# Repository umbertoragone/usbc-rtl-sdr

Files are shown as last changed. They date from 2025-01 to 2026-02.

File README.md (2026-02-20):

# USB-C RTL-SDR mod
An adapter board to convert your RTL-SDR V3 or V4 USB-A (male) to USB-C (female). **Available for purchase on [Tindie](https://www.tindie.com/products/ragone/usb-c-rtl-sdr-v3v4-mod/) or [Lectronz](https://lectronz.com/products/usb-c-rtl-sdr-v3-v4-mod)!**

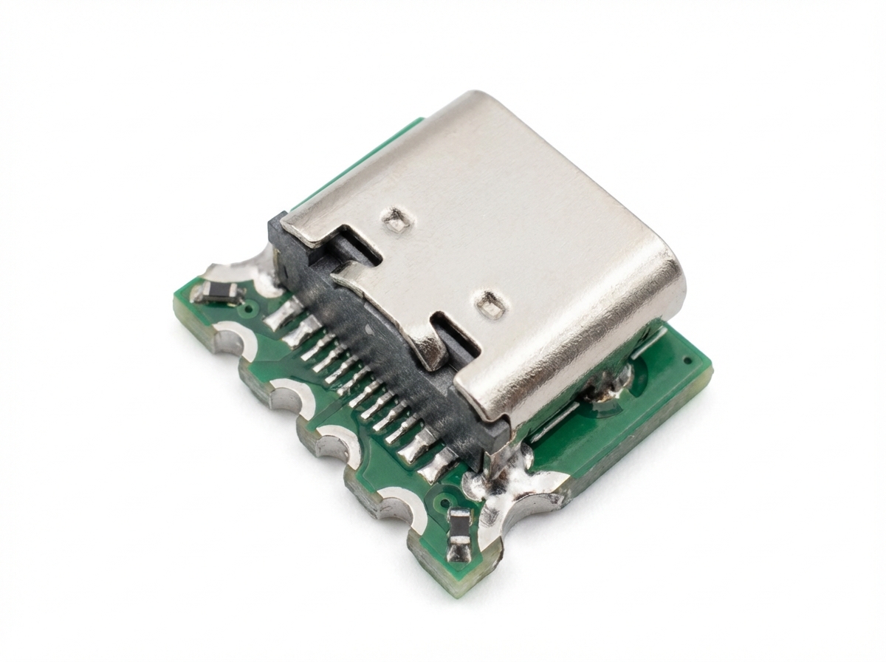
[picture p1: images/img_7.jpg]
USB-C adapter board


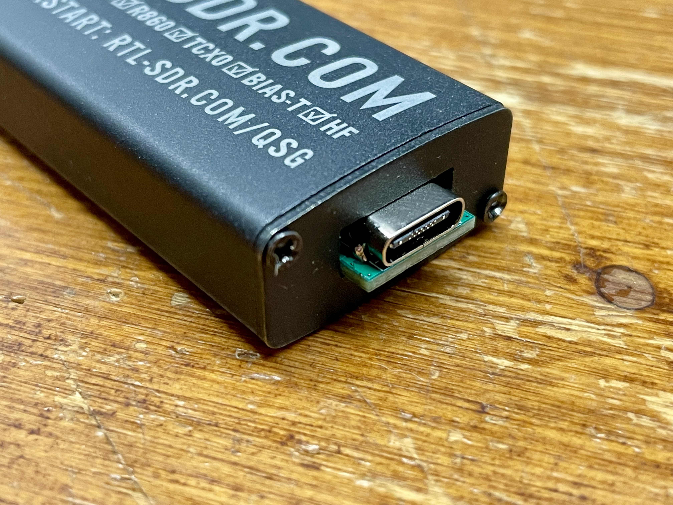
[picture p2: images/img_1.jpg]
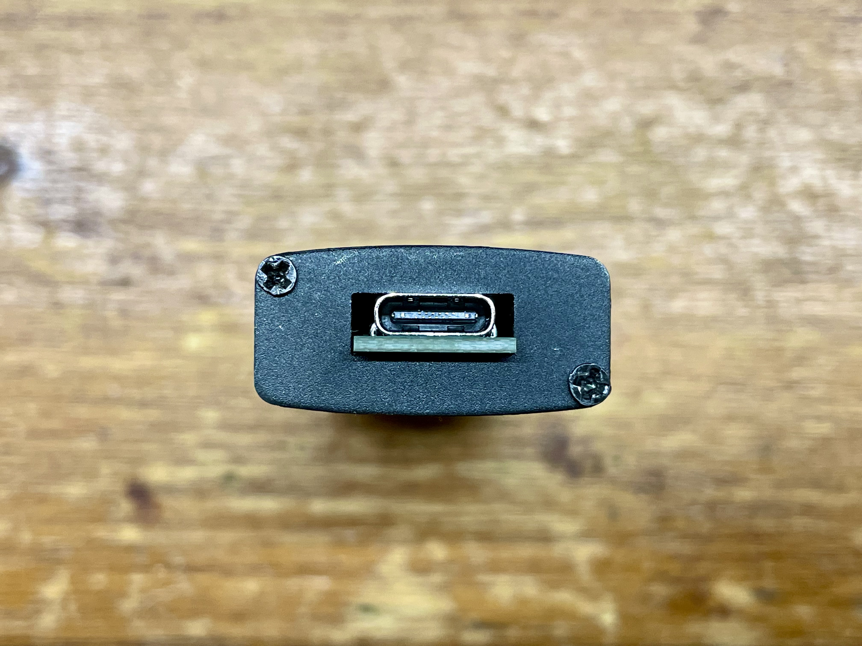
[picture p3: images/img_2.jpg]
 

## Kicad files
If you want to open and modify the original project in Kicad 8 (>=8.0.7), you can find both the `.kicad_sch` and `.kicad_pcb` files in the `kicad` folder in this repository. I recommend you use the latest Kicad 8 version available for better compatibility.

## Gerber files
If you want to fabricate your own PCBs from a PCB manufacturer of your choice, you can go ahead and download the `Gerber-v1.x.zip` file from the `gerber` folder in this repository. Upload it or send it to the PCB fabrication house and select the following specifications (if not already filled out):
- **Layers**: 2
- **PCB Thickness**: 1.2 mm
- **PCB Color**: any (green is usually cheaper and faster to produce, but black also looks nice and might blend with the black outer case)
- **Surface finish**: HASL or ENIG (gold plating)
- **Outer Copper Weight**: 1 oz
- **Via Covering**: Tented
- **Mark on PCB**: Remove Mark (JLCPCB specific, now free of charge)
- **Castellated holes**: Yes

## BOM and assembly

Included in this repository is the HTML BOM (`ibom.html`) to help you in the assembly/soldering process after you received your PCBs. You can [access the Interactive HTML BOM here](https://umbertoragone.github.io/usbc-rtl-sdr/bom/ibom.html), without having to download the .html file. Also, here is the list of components you will have to source and solder yourself:

| Reference(s) | Value | Footprint | LCSC Part # | Qty |
| --- | --- | --- | --- | --- |
| R1, R2 | 5k1 1% | R_0402_1005Metric | [C25905](https://www.lcsc.com/product-detail/C25905.html) | 2 |
| USB1 | USB_C_Receptacle_USB2.0 | TYPE-C-31-M-12 | [C2988369](https://www.lcsc.com/product-detail/C2988369.html) | 1 |

## How to perform the mod
1. Open the case of your RTL-SDR dongle by unscrewing the 2 screws on the USB A side.
2. Unscrew the locking nut on the SMA connector and make sure to remember the order they go in.
3. Carefully slide out the PCB from the metal housing.
4. Desolder the USB A connector from the board and clean the pads from any residual solder.
5. Position the USB C adapter board in place of the old USB A connector, like in the pictures, and tack it in place with some solder.
6. Solder all of the pins, including the two GND pads on the left and right sides of the USB C adapter board for mechanical strength.
7. (Optional) Clean the PCB and the soldered joints using 99.9% IPA (isopropyl alcohol).
8. Slide the board back in its metal housing, being careful of the thermal adhesive pad on the bottom of the PCB.
9. Lock the SMA connector in place and screw back the front panel of the metal housing (on the USB side).
10. Enjoy the USB C mod!

## Prebuilt option
If you're looking for an adapter board that's already assembled and ready to install on your RTL-SDR dongle, I offer a prebuilt option that's perfect for those who want a plug-and-play solution without the hassle of sourcing and assembling components. Each board is handcrafted and fully tested before shipping. **[Check it out on my Tindie store](https://www.tindie.com/products/ragone/usb-c-rtl-sdr-v3v4-mod/) or on [Lectronz](https://lectronz.com/products/usb-c-rtl-sdr-v3-v4-mod)**.

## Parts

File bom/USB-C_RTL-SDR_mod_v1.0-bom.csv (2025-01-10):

Comment | Designator | Footprint | LCSC
USB_C_Receptacle_USB2.0 | J1 | USB_C:TYPE-C-31-M-12 | C2988369
5k1 | R1,R2 | Resistor_SMD:R_0402_1005Metric | C25905

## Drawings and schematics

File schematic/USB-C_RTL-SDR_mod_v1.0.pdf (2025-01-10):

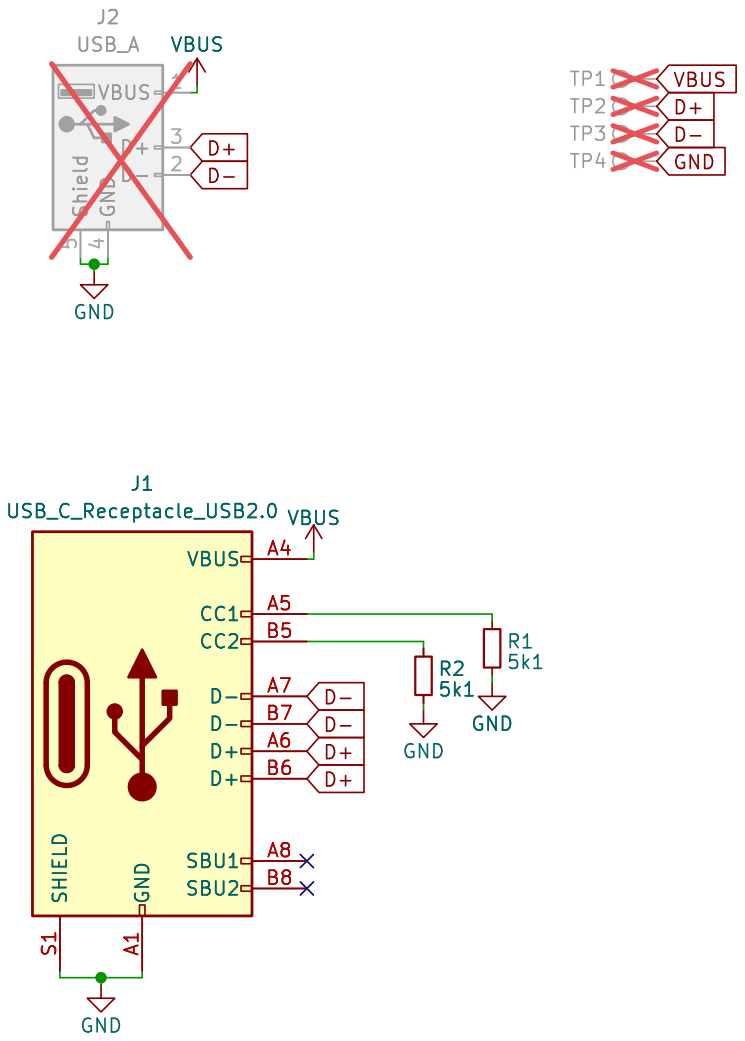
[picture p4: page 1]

Id: 1/1 Title: USB-C RTL-SDR mod

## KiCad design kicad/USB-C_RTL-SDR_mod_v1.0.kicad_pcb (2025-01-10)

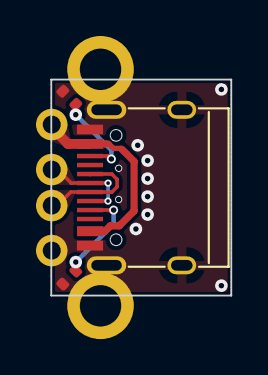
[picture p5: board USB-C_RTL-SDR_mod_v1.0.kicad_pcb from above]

Board: 2 copper layers, 10.0 x 12.0 mm, 4 parts (0 on the bottom side), 6 nets.

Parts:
J1: USB_C_Receptacle_USB2.0; TYPE-C-31-M-12
J2: USB_A; USB_A_CONNFLY_DS1095-WNR0
R1, R2: 5k1; R_0402_1005Metric

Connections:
D+: J1.A6 (D+), J1.B6 (D+), J2.3 (D+)
D-: J1.A7 (D-), J1.B7 (D-), J2.2 (D-)
GND: J1.A1 (GND), J1.A12 (GND), J1.B1 (GND), J1.B12 (GND), J1.S1 (SHIELD), J2.4 (GND), J2.5 (Shield), R1.1, R2.1
unnamed: J1.A5 (CC1), R1.2
unnamed: J1.B5 (CC2), R2.2
VBUS: J1.A4 (VBUS), J1.A9 (VBUS), J1.B4 (VBUS), J1.B9 (VBUS), J2.1 (VBUS)

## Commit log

2025-01-10 Add README.md with project details and manufacturing instructions
    [USB-C_RTL-SDR_mod_v1.0.kicad_pcb, USB-C_RTL-SDR_mod_v1.0.kicad_sch]
2025-01-10 Update component properties in schematic: modify BOM inclusion and DNP status for several components, and add LCSC properties for new components.
    [USB-C_RTL-SDR_mod_v1.0.kicad_pcb, USB-C_RTL-SDR_mod_v1.0.kicad_sch]
2025-01-10 Add csv BOM and top position files for PCBA
    [USB-C_RTL-SDR_mod_v1.0-bom.csv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]
2026-02-20 Fix screw count in RTL-SDR dongle mod instructions
    Corrected the number of screws to unscrew for opening the RTL-SDR dongle case.
